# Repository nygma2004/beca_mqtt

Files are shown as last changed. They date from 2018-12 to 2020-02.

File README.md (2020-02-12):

# Beca thermostat Modbus to MQTT Gateway
This sketch is designed to provide an MQTT gateway to Beca Modbus thermostats. It uses a ESP8266 (in my case Wemos D1 mini) and an RS485 to TTL converter to read the Holding Registers of the thermostat and publish those values to MQTT. Also subscirbes to MQTT and relevant updates are written into the Modbus device (like power status, fan speed, mode, target temperature and screen lock).

Project explained in detail in this video: https://youtu.be/d8nhMimx9-0

## Libraries used
- Modbus Master library: https://github.com/4-20ma/ModbusMaster/blob/master/examples/RS485_HalfDuplex/RS485_HalfDuplex.ino
- ESP Software Serial: https://github.com/plerup/espsoftwareserial
- PubSubClient: handle MQTT communication. Install it from the Arduino Library Manager
- Time by Michael Margolis: also install this from the Arduino Library Manager
- SunMoon: sunrise and sunset calculation: https://github.com/sfrwmaker/sunMoon

## Wiring
```
Wemod D1 mini (or other ESP)            TTL to RS485
D1                                      DE
D2                                      RE
D5                                      RO
D6                                      DI
5V                                      VCC
G(GND)                                  GND
```
Red Modbus wire goes to the RS486 "A" screw terminals and black to "B".

## MQTT topic
Root topic is defined in the beginning of the sketch and the full topic gets appended to this. I specified "/beca/" as my root, so my topic are e.g. "/beca/read/power". Values read from the device have "read" in the topic, and values sent to the thermostat have "write". Sending messages to the "read" topics get ignored. There is no error handling on the payload of the "write" messages, data received gets sent to the device.
### Read topics (Published topics)
- root + "read/power": device status, Off (0) or On (1)
- root + "read/fan": fan speed, Auto (0), High (1), Medium (2), Low (3)
- root + "read/mode": mode, Cooling (0), Heating (1), Ventillation (2)
- root + "read/time": hour and time on the device in HH:MM format
- root + "read/weekday": weekday on the device: Monday (1), ... Sunday (7)
- root + "read/valve": valve state, Closed (0), Open (1)
- root + "read/lock" : screen lock, Unlocked (0), Locked (1)
- root + "read/ambient": ambient temperature in degrees centigrade, e.g. 24.5
- root + "read/target": target temperature in degrees centigrade, e.g. 20.5
- root + "rssi": wifi signal strength (RSSI)
- root + "uptime": uptime in minutes
### Write topics (Subscribed topics)
- root + "write/power": set device status (same values as above)
- root + "write/fan": set fan speed (same values as above)
- root + "write/mode": set mode (same values as above)
- root + "write/lock" : set screen lock  (same values as above)
- root + "write/target": set target temperature in degrees centigrade, e.g. 20.5
### Error topic (published)
- root + "error": Modbus error message in text (e.g. "Response timed out")

## Test board shown in the video
This is the general layout of the board showing how the Wemos D1 mini and the RS485 board is oriented:
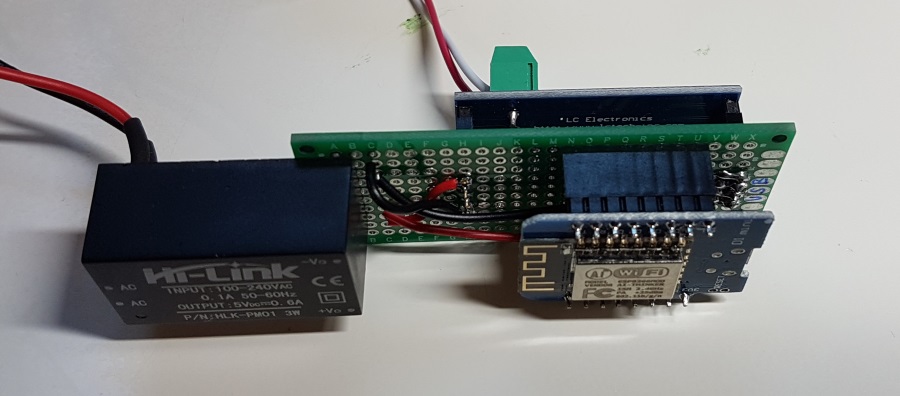
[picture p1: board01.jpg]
General board layout


This is the side where the Wemos plugs in. You see the red +5V wires connected to the 5V pin of the Wemos and Vcc of the RS486 board. Black goes to GND on both:
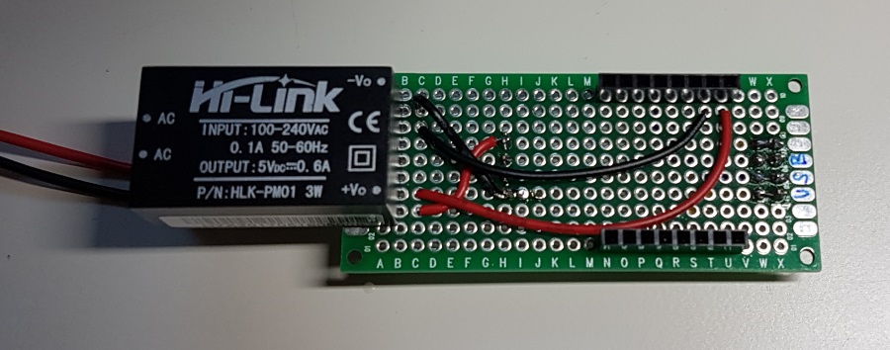
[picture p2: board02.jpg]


And the other side of the board where the RS485 plugs. Yellow wires are the data wires, blue are the enable wires:
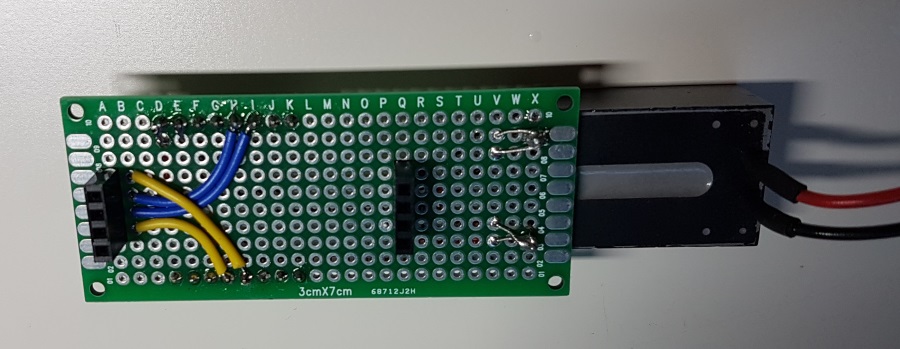
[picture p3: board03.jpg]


## Node-Red
There is an example Node-Red flow (also shown in the video), which shows how to communicate with the device from Node-Red. The flow is in Gitbuh, and also here: https://flows.nodered.org/flow/286a8cea2fbb2a60544f0dd2faefda2a

## PCB
I have also designed a PCB for this board. You can see my PCB project at PCBWay where you can order the PCB but you can also download the gerber files if you want to manufacture elsewhere: https://www.pcbway.com/project/shareproject/ESP8266_Modbus_board.html
You can find the BOM on the PCBWay project page. I purchased most of the components on eBay, but some of the links do not work any more. But only the RS486 to TTL converter is "special" everything else can be found in many different places, like Aliexpress.

## Custom Case
I have design a 3D printable case for the board, you find all the information in the case folder.

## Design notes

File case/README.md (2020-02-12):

This is a 3D printable case for this modbus board. I am not saying this is the most sofisticated case ever. I am fairly new to Fusion 360 as well, so feel free to edit my design and change stuff around. The basic design is parametric, so you can increase the wall thickness or general size, but the mounting points and the wholes are measured from the side, so those need to be re-aligned.
In the files, you find the Fusion 360 model, STL files and gcode as well. Slicing was done for a 3D printer with 0.2 mm layer height, 0.4 mm nozzle, 20% infill with brim.

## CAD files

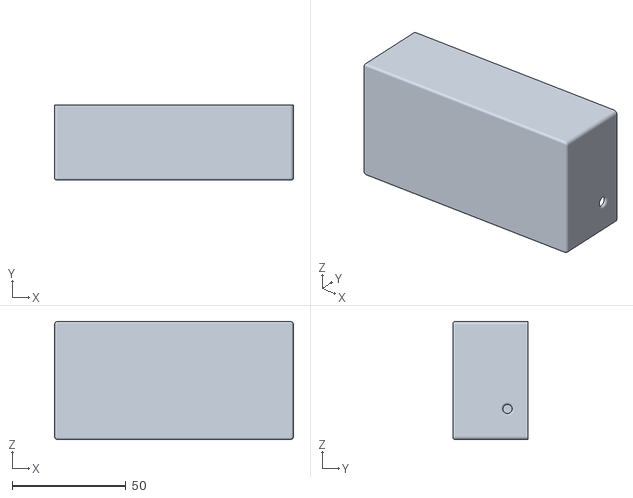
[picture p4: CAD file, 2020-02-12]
case/modbus_case_body.stl
105.0 x 33.0 x 52.0

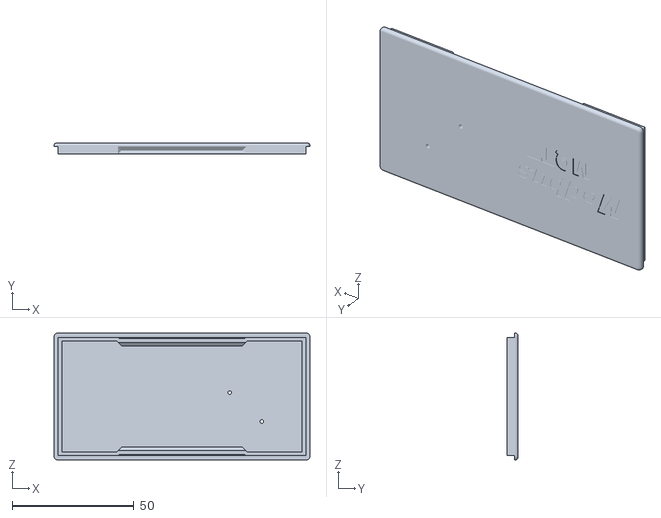
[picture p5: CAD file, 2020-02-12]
case/modbus_case_top.stl
105.0 x 4.50 x 52.0

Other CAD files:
case/Modbus case.f3d

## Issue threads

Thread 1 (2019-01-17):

Issue on NodeMCU

jongerenchaos, 2019-01-17:
I upload the code to my node MCU ESP12E (with arduino version 1.8.5 with esp8266 boardversion 2.4.2). Compiling is OK en uploading is no problem.

But when i run the software i get a error. Can you help me to resolve this issue?

`Beca Modbus to MQTT Gateway
Connecting to Wifi........
Connected to wifi network
IP address: 192.168.1.137
Signal [RSSI]: -38
Modbus connection is set up
MDNS responder started
HTTP server started
Starting UDP
Local port: 2390
Requesting NTP update from 212.92.16.193
Sending NTP packet...
Attempting MQTT connection...connected
NTP Update (epoch): 1547765862
NTP Update (time): 17-01-2019 22:57:42
Modbus minute update failed: Response timed out
Error: Response timed out

Exception (9):
epc1=0x40104b14 epc2=0x00000000 epc3=0x00000000 excvaddr=0x00000003 depc=0x00000000

ctx: sys
sp: 3fffec00 end: 3fffffb0 offset: 01a0

>>>stack>>>
3fffeda0:  0024dce3 00000494 3fff1984 40205409
3fffedb0:  3fffee50 7fffffff 0000025c 00000021
3fffedc0:  3ffef674 0000001f 00000002 40209364
3fffedd0:  0000001f 000012b8 00000257 00000005
3fffede0:  3fffc278 40101fe8 3ffef674 3fff1cd4
3fffedf0:  00000000 00000012 3ffef674 402095b8
3fffee00:  40104d40 0026cec4 3fff0318 00000000
3fffee10:  3ffeef30 3fff0318 3fff0420 3fff0400
3fffee20:  00000000 0026c8aa 40201504 00000005
3fffee30:  3fff0318 000000e2 3fff0400 40209f50
3fffee40:  3fff08b4 3ffe8bb8 000000e2 40202c65
3fffee50:  6365622f 72652f61 00726f72 3fff1494
3fffee60:  00000000 3fff1c5c 3fff1cc8 40218c08
3fffee70:  00000000 4bc6a7f0 f1a9fbe7 00000000
3fffee80:  00001810 00000000 4bc6a7f0 00000000
3fffee90:  40229fb5 00186a00 401067a8 40209cdf
3fffeea0:  3fff1cd4 0000001f 00000012 4020b290
3fffeeb0:  000000e2 3ffef508 3fff0420 40202f8a
3fffeec0:  3fff03fc 0000000a 401067a8 00001808
3fffeed0:  00000000 3ffe98fc 3fff0a6c 40212ec8
3fffeee0:  001bc98c 3ffe9a84 00000041 3fff0570
3fffeef0:  40213004 3fff0574 3ffe98fc 60000600
3fffef00:  005ddcb9 3fff0574 3ffeef08 40213095
3fffef10:  40104b6e 3fff016c 0017fde0 00000000
3fffef20:  40231878 3fff016c 3ffeef30 60000600
3fffef30:  005ddcb9 3ffeef30 3fff016c 40231885
3fffef40:  402318ca 3fffdab0 00000000 3fffdcb0
3fffef50:  3ffeef50 3fffdab0 00000000 4020ab0b
3fffef60:  40000f49 40000f49 3fffdab0 40000f49
3fffef70:  40000e19 40001878 00000002 0000000d
3fffef80:  3fffff10 aa55aa55 000000b4 40104424
3fffef90:  4010442a 00000002 0000000d 0c634b24
3fffefa0:  4010000d 3415490f 4de23e89 7f0d72e0
3fffefb0:  40100774 3fffef4c 40100721 3ffffee8
3fffefc0:  3fffffd0 00000000 00000000 feefeffe
3fffefd0:  feefeffe feefeffe feefeffe feefeffe
3fffefe0:  feefeffe feefeffe feefeffe feefeffe
3fffeff0:  feefeffe feefeffe feefeffe feefeffe
3ffff000:  feefeffe feefeffe feefeffe feefeffe
3ffff010:  feefeffe feefeffe feefeffe feefeffe
3ffff020:  feefeffe feefeffe feefeffe feefeffe
3ffff030:  feefeffe feefeffe feefeffe feefeffe
3ffff040:  feefeffe feefeffe feefeffe feefeffe
3ffff050:  feefeffe feefeffe feefeffe feefeffe
3ffff060:  feefeffe feefeffe feefeffe feefeffe
3ffff070:  feefeffe feefeffe feefeffe feefeffe
3ffff080:  feefeffe feefeffe feefeffe feefeffe
3ffff090:  feefeffe feefeffe feefeffe feefeffe
3ffff0a0:  feefeffe feefeffe feefeffe feefeffe
3ffff0b0:  feefeffe feefeffe feefeffe feefeffe
3ffff0c0:  feefeffe feefeffe feefeffe feefeffe
3ffff0d0:  feefeffe feefeffe feefeffe feefeffe
3ffff0e0:  feefeffe feefeffe feefeffe feefeffe
3ffff0f0:  feefeffe feefeffe feefeffe feefeffe
3ffff100:  feefeffe feefeffe feefeffe feefeffe
3ffff110:  feefeffe feefeffe feefeffe feefeffe
3ffff120:  feefeffe feefeffe feefeffe feefeffe
3ffff130:  feefeffe feefeffe feefeffe feefeffe
3ffff140:  feefeffe feefeffe feefeffe feefeffe
3ffff150:  feefeffe feefeffe feefeffe feefeffe
3ffff160:  feefeffe feefeffe feefeffe feefeffe
3ffff170:  feefeffe feefeffe feefeffe feefeffe
3ffff180:  feefeffe feefeffe feefeffe feefeffe
3ffff190:  feefeffe feefeffe feefeffe feefeffe
3ffff1a0:  feefeffe feefeffe feefeffe feefeffe
3ffff1b0:  feefeffe feefeffe feefeffe feefeffe
3ffff1c0:  feefeffe feefeffe feefeffe feefeffe
3ffff1d0:  feefeffe feefeffe feefeffe feefeffe
3ffff1e0:  feefeffe feefeffe feefeffe feefeffe
3ffff1f0:  feefeffe feefeffe feefeffe feefeffe
3ffff200:  feefeffe feefeffe feefeffe feefeffe
3ffff210:  feefeffe feefeffe feefeffe feefeffe
3ffff220:  feefeffe feefeffe feefeffe feefeffe
3ffff230:  feefeffe feefeffe feefeffe feefeffe
3ffff240:  feefeffe feefeffe feefeffe feefeffe
3ffff250:  feefeffe feefeffe feefeffe feefeffe
3ffff260:  feefeffe feefeffe feefeffe feefeffe
3ffff270:  feefeffe feefeffe feefeffe feefeffe
3ffff280:  feefeffe feefeffe feefeffe feefeffe
3ffff290:  feefeffe feefeffe feefeffe feefeffe
3ffff2a0:  feefeffe feefeffe feefeffe feefeffe
3ffff2b0:  feefeffe feefeffe feefeffe feefeffe
3ffff2c0:  feefeffe feefeffe feefeffe feefeffe
3ffff2d0:  feefeffe feefeffe feefeffe feefeffe
3ffff2e0:  feefeffe feefeffe feefeffe feefeffe
3ffff2f0:  feefeffe feefeffe feefeffe feefeffe
3ffff300:  feefeffe feefeffe feefeffe feefeffe
3ffff310:  feefeffe feefeffe feefeffe feefeffe
3ffff320:  feefeffe feefeffe feefeffe feefeffe
3ffff330:  feefeffe feefeffe feefeffe feefeffe
3ffff340:  feefeffe feefeffe feefeffe feefeffe
3ffff350:  feefeffe feefeffe feefeffe feefeffe
3ffff360:  feefeffe feefeffe feefeffe feefeffe
3ffff370:  feefeffe feefeffe feefeffe feefeffe
3ffff380:  feefeffe feefeffe feefeffe feefeffe
3ffff390:  feefeffe feefeffe feefeffe feefeffe
3ffff3a0:  feefeffe feefeffe feefeffe feefeffe
3ffff3b0:  feefeffe feefeffe feefeffe feefeffe
3ffff3c0:  feefeffe feefeffe feefeffe feefeffe
3ffff3d0:  feefeffe feefeffe feefeffe feefeffe
3ffff3e0:  feefeffe feefeffe feefeffe feefeffe
3ffff3f0:  feefeffe feefeffe feefeffe feefeffe
3ffff400:  feefeffe feefeffe feefeffe feefeffe
3ffff410:  feefeffe feefeffe feefeffe feefeffe
3ffff420:  feefeffe feefeffe feefeffe feefeffe
3ffff430:  feefeffe feefeffe feefeffe feefeffe
3ffff440:  feefeffe feefeffe feefeffe feefeffe
3ffff450:  feefeffe feefeffe feefeffe feefeffe
3ffff460:  feefeffe feefeffe feefeffe feefeffe
3ffff470:  feefeffe feefeffe feefeffe feefeffe
3ffff480:  feefeffe feefeffe feefeffe feefeffe
3ffff490:  feefeffe feefeffe feefeffe feefeffe
3ffff4a0:  feefeffe feefeffe feefeffe feefeffe
3ffff4b0:  feefeffe feefeffe feefeffe feefeffe
3ffff4c0:  feefeffe feefeffe feefeffe feefeffe
3ffff4d0:  feefeffe feefeffe feefeffe feefeffe
3ffff4e0:  feefeffe feefeffe feefeffe feefeffe
3ffff4f0:  feefeffe feefeffe feefeffe feefeffe
3ffff500:  feefeffe feefeffe feefeffe feefeffe
3ffff510:  feefeffe feefeffe feefeffe feefeffe
3ffff520:  feefeffe feefeffe feefeffe feefeffe
3ffff530:  feefeffe feefeffe feefeffe feefeffe
3ffff540:  feefeffe feefeffe feefeffe feefeffe
3ffff550:  feefeffe feefeffe feefeffe feefeffe
3ffff560:  feefeffe feefeffe feefeffe feefeffe
3ffff570:  feefeffe feefeffe feefeffe feefeffe
3ffff580:  feefeffe feefeffe feefeffe feefeffe
3ffff590:  feefeffe feefeffe feefeffe feefeffe
3ffff5a0:  feefeffe feefeffe feefeffe feefeffe
3ffff5b0:  feefeffe feefeffe feefeffe feefeffe
3ffff5c0:  feefeffe feefeffe feefeffe feefeffe
3ffff5d0:  feefeffe feefeffe feefeffe feefeffe
3ffff5e0:  feefeffe feefeffe feefeffe feefeffe
3ffff5f0:  feefeffe feefeffe feefeffe feefeffe
3ffff600:  feefeffe feefeffe feefeffe feefeffe
3ffff610:  feefeffe feefeffe feefeffe feefeffe
3ffff620:  feefeffe feefeffe feefeffe feefeffe
3ffff630:  feefeffe feefeffe feefeffe feefeffe
3ffff640:  feefeffe feefeffe feefeffe feefeffe
3ffff650:  feefeffe feefeffe feefeffe feefeffe
3ffff660:  feefeffe feefeffe feefeffe feefeffe
3ffff670:  feefeffe feefeffe feefeffe feefeffe
3ffff680:  feefeffe feefeffe feefeffe feefeffe
3ffff690:  feefeffe feefeffe feefeffe feefeffe
3ffff6a0:  feefeffe feefeffe feefeffe feefeffe
3ffff6b0:  feefeffe feefeffe feefeffe feefeffe
3ffff6c0:  feefeffe feefeffe feefeffe feefeffe
3ffff6d0:  feefeffe feefeffe feefeffe feefeffe
3ffff6e0:  feefeffe feefeffe feefeffe feefeffe
3ffff6f0:  feefeffe feefeffe feefeffe feefeffe
3ffff700:  feefeffe feefeffe feefeffe feefeffe
3ffff710:  feefeffe feefeffe feefeffe feefeffe
3ffff720:  feefeffe feefeffe feefeffe feefeffe
3ffff730:  feefeffe feefeffe feefeffe feefeffe
3ffff740:  feefeffe feefeffe feefeffe feefeffe
3ffff750:  feefeffe feefeffe feefeffe feefeffe
3ffff760:  feefeffe feefeffe feefeffe feefeffe
3ffff770:  feefeffe feefeffe feefeffe feefeffe
3ffff780:  feefeffe feefeffe feefeffe feefeffe
3ffff790:  feefeffe feefeffe feefeffe feefeffe
3ffff7a0:  feefeffe feefeffe feefeffe feefeffe
3ffff7b0:  feefeffe feefeffe feefeffe feefeffe
3ffff7c0:  feefeffe feefeffe feefeffe feefeffe
3ffff7d0:  feefeffe feefeffe feefeffe feefeffe
3ffff7e0:  feefeffe feefeffe feefeffe feefeffe
3ffff7f0:  feefeffe feefeffe feefeffe feefeffe
3ffff800:  feefeffe feefeffe feefeffe feefeffe
3ffff810:  feefeffe feefeffe feefeffe feefeffe
3ffff820:  feefeffe feefeffe feefeffe feefeffe
3ffff830:  feefeffe feefeffe feefeffe feefeffe
3ffff840:  feefeffe feefeffe feefeffe feefeffe
3ffff850:  feefeffe feefeffe feefeffe feefeffe
3ffff860:  feefeffe feefeffe feefeffe feefeffe
3ffff870:  feefeffe feefeffe feefeffe feefeffe
3ffff880:  feefeffe feefeffe feefeffe feefeffe
3ffff890:  feefeffe feefeffe feefeffe feefeffe
3ffff8a0:  feefeffe feefeffe feefeffe feefeffe
3ffff8b0:  feefeffe feefeffe feefeffe feefeffe
3ffff8c0:  feefeffe feefeffe feefeffe feefeffe
3ffff8d0:  feefeffe feefeffe feefeffe feefeffe
3ffff8e0:  feefeffe feefeffe feefeffe feefeffe
3ffff8f0:  feefeffe feefeffe feefeffe feefeffe
3ffff900:  feefeffe feefeffe feefeffe feefeffe
3ffff910:  feefeffe feefeffe feefeffe feefeffe
3ffff920:  feefeffe feefeffe feefeffe feefeffe
3ffff930:  feefeffe feefeffe feefeffe feefeffe
3ffff940:  feefeffe feefeffe feefeffe feefeffe
3ffff950:  feefeffe feefeffe feefeffe feefeffe
3ffff960:  feefeffe feefeffe feefeffe feefeffe
3ffff970:  feefeffe feefeffe feefeffe feefeffe
3ffff980:  feefeffe feefeffe feefeffe feefeffe
3ffff990:  feefeffe feefeffe feefeffe feefeffe
3ffff9a0:  feefeffe feefeffe feefeffe feefeffe
3ffff9b0:  feefeffe feefeffe feefeffe feefeffe
3ffff9c0:  feefeffe feefeffe feefeffe feefeffe
3ffff9d0:  feefeffe feefeffe feefeffe feefeffe
3ffff9e0:  feefeffe feefeffe feefeffe feefeffe
3ffff9f0:  feefeffe feefeffe feefeffe feefeffe
3ffffa00:  feefeffe feefeffe feefeffe feefeffe
3ffffa10:  feefeffe feefeffe feefeffe feefeffe
3ffffa20:  feefeffe feefeffe feefeffe feefeffe
3ffffa30:  feefeffe feefeffe feefeffe feefeffe
3ffffa40:  feefeffe feefeffe feefeffe feefeffe
3ffffa50:  feefeffe feefeffe feefeffe feefeffe
3ffffa60:  feefeffe feefeffe feefeffe feefeffe
3ffffa70:  feefeffe feefeffe feefeffe feefeffe
3ffffa80:  feefeffe feefeffe feefeffe feefeffe
3ffffa90:  feefeffe feefeffe feefeffe feefeffe
3ffffaa0:  feefeffe feefeffe feefeffe feefeffe
3ffffab0:  feefeffe feefeffe feefeffe feefeffe
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
jongerenchaos, 2019-01-18:
Update: I get the same results with a ESP01 or another ESP device, also with another ESP boardversion or Arduino version

nygma2004, 2019-01-18:
Sorry, I am on a business trip, I could not respond to your query in time. The only time I got a short dump when was before I disabled the watchdog timer. But that is done in code so it should not impact you.

I can see that the rst cause:2 which is the reset pin. Are you using the reset pin for something? It looks like something is pulling the reset pin. Did you wire your module same as mine?

jongerenchaos, 2019-01-18:
Thanks for your fast reply!

Yep the wires are exactly the same as yours. Maybe that i have a thermostat which not support modbus or something (or missing the modbus components)? Can you send some images from the PCB from your thermostat, so that i can add some missing components or something....?

Here are some images from the thermostat who i used:
https://pilo.ovh/image/SpNQg
https://pilo.ovh/image/SpJEx

nygma2004, 2019-01-19:
Oh, so this looks same but not exactly Beca. So mine actually had a red and white wire coming out at the back which was marked modbus. I have never opened the case.

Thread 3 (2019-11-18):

State all the libraries

ngalfas, 2019-11-18:
Hi, just trying your code.  I saw the README stating 2 libraries.
ModbusMaster  which needs to be added to the Arduino IDE and EspSoftware Special which is already  available when ESP8266 installs its board package.

Also there are some more libraries need to be installed.
PubSubClient, Time and sunMoon.

The first two i found on the Libraries Manager.
I can't find the sunMoon Library. There is no such library on the Manager.
Even searched for it but still not sure.
Maybe you can clarify this and add these to the README?

ngalfas, 2019-11-19:
when i had a better look on the code, i saw you commented all the daylight calculations.
so i just removed all of the sunMoon references from the code.

nygma2004, 2019-11-19:
Sorry for the slow response. I have updated the readme.

Closed 2019-11-19.

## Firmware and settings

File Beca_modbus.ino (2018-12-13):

)#include <SoftwareSerial.h>       // Leave the main serial line (USB) for debugging and flashing
#include <ModbusMaster.h>         // Modbus master library for ESP8266
#include <ESP8266WiFi.h>          // Wifi connection
#include <ESP8266WebServer.h>     // Web server for general HTTP response
#include <ESP8266mDNS.h>          // mDNS
#include <PubSubClient.h>         // MQTT support
#include <WiFiUdp.h>                // Added for NTP functionality
#include <Time.h>
#include <TimeLib.h>
#include <sunMoon.h>                // Sunrise, sunset calculation
#include "NTP.h"

#define MODBUS_RATE     9600      // Modbus speed of Beca, do not change
#define SERIAL_RATE     115200    // Serial speed for status info
#define MAX485_DE       5         // D1, DE pin on the TTL to RS485 converter
#define MAX485_RE_NEG   4         // D2, RE pin on the TTL to RS485 converter
#define MAX485_RX       14        // D5, RO pin on the TTL to RS485 converter
#define MAX485_TX       12        // D6, DI pin on the TTL to RS485 converter
#define SLAVE_ID        1         // Default slave ID of Beca
#define STATUS_LED      2         // Status LED on the Wemos D1 mini (D4)
#define UPDATE_MODBUS   1         // 1: modbus device is read every second
#define UPDATE_STATUS   10        // 10: status mqtt message is sent every 10 seconds

// Update the below parameters for your project
// Also check NTP.h for some parameters as well
const char* ssid = "xxxxxxxxxxxxx";           // Wifi SSID
const char* password = "xxxxxxxxxxxxxxxx";    // Wifi password
const char* mqtt_server = "192.168.x.xx";     // MQTT server
const char* mqtt_user = "xxxxxx";             // MQTT userid
const char* mqtt_password = "xxxxxx";         // MQTT password
const char* clientID = "Beca";                // MQTT client ID
const char* topicRoot = "/beca/";             // MQTT root topic for the device, keep / at the end

String NTPtime = "--:--";
char msg[50];
String mqttStat = "";
String message = "";
unsigned long lastTick, uptime, lastNTP, seconds;

os_timer_t myTimer;
MDNSResponder mdns;
ESP8266WebServer server(80);
WiFiClient espClient;
PubSubClient mqtt(mqtt_server, 1883, 0, espClient);
SoftwareSerial modbus(MAX485_RX, MAX485_TX, false, 256); //RX, TX
ModbusMaster beca;

void preTransmission() {
  digitalWrite(MAX485_RE_NEG, 1);
  digitalWrite(MAX485_DE, 1);
}

void postTransmission() {
  digitalWrite(MAX485_RE_NEG, 0);
  digitalWrite(MAX485_DE, 0);
}

void sendModbusError(uint8_t result) {
  String message = "";
  if (result==beca.ku8MBIllegalFunction) {
    message = "Illegal function";
  }
  if (result==beca.ku8MBIllegalDataAddress) {
    message = "Illegal data address";
  }
  if (result==beca.ku8MBIllegalDataValue) {
    message = "Illegal data value";
  }
  if (result==beca.ku8MBSlaveDeviceFailure) {
    message = "Slave device failure";
  }
  if (result==beca.ku8MBInvalidSlaveID) {
    message = "Invalid slave ID";
  }
  if (result==beca.ku8MBInvalidFunction) {
    message = "Invalid function";
  }
  if (result==beca.ku8MBResponseTimedOut) {
    message = "Response timed out";
  }
  if (result==beca.ku8MBInvalidCRC) {
    message = "Invalid CRC";
  }
  if (message=="") {
    message = result;
  }
  Serial.println(message);    
  char topic[80];
  char value[30];
  sprintf(topic,"%serror",topicRoot);
  mqtt.publish(topic, message.c_str());
  delay(5);
}

// This is the 1 second timer callback function
void timerCallback(void *pArg) {
  seconds++;
  // Query the modbus device 
  if (seconds % UPDATE_MODBUS==0) {
    uint8_t result;
    //uint16_t data[6];

    digitalWrite(STATUS_LED, 0);
    ESP.wdtDisable();
    result = beca.readHoldingRegisters(0,10);
    ESP.wdtEnable(1);
    if (result == beca.ku8MBSuccess)   {
      char topic[80];
      char value[10];
      // Power
      sprintf(topic,"%sread/power",topicRoot);
      sprintf(value,"%d",beca.getResponseBuffer(0x00));
      //itoa(beca.getResponseBuffer(0x00),value,10);
      mqtt.publish(topic, value);
      Serial.print(F("Power: "));
      Serial.print(value);
      //yield();
      // Fan
      sprintf(topic,"%sread/fan",topicRoot);
      sprintf(value,"%d",beca.getResponseBuffer(0x01));
      //itoa(beca.getResponseBuffer(0x01),value,10);
      mqtt.publish(topic, value);
      Serial.print(F(", Fan: "));
      Serial.print(value);
      //yield();
      // Mode
      sprintf(topic,"%sread/mode",topicRoot);
      //sprintf(value,"%d",beca.getResponseBuffer(0x02));
      itoa(beca.getResponseBuffer(0x02),value,10);
      mqtt.publish(topic, value);
      Serial.print(F(", Mode: "));
      Serial.print(value);
      //yield();
      // Target temperature
      sprintf(topic,"%sread/target",topicRoot);
      sprintf(value,"%.1f",beca.getResponseBuffer(0x03)/10.0f);
      mqtt.publish(topic, value);
      Serial.print(F(", Target: "));
      Serial.print(value);
      //yield();
      // Ambient
      sprintf(topic,"%sread/ambient",topicRoot);
      sprintf(value,"%.1f",beca.getResponseBuffer(0x08)/10.0f);
      mqtt.publish(topic, value);
      Serial.print(F(", Ambient: "));
      Serial.print(value);
      //yield();
      // Lock
      sprintf(topic,"%sread/lock",topicRoot);
      sprintf(value,"%d",beca.getResponseBuffer(0x04));
      mqtt.publish(topic, value);
      Serial.print(F(", Lock: "));
      Serial.print(value);
      //yield();
      // Valve
      sprintf(topic,"%sread/valve",topicRoot);
      sprintf(value,"%d",beca.getResponseBuffer(0x09));
      mqtt.publish(topic, value);
      Serial.print(F(", Valve: "));
      Serial.print(value);
      //yield();
      // Weekday
      sprintf(topic,"%sread/weekday",topicRoot);
      sprintf(value,"%d",beca.getResponseBuffer(0x07));
      mqtt.publish(topic, value);
      Serial.print(F(", Weekday: "));
      Serial.print(value);
      //yield();
      // Time
      sprintf(topic,"%sread/time",topicRoot);
      sprintf(value,"%02d:%02d",beca.getResponseBuffer(0x06),beca.getResponseBuffer(0x05));
      mqtt.publish(topic, value);
      Serial.print(F(", Time: "));
      Serial.println(value);
    } else {
      Serial.print(F("Error: "));
      sendModbusError(result);
    }
    digitalWrite(STATUS_LED, 1);

  }
  // Send RSSI and uptime status
  if (seconds % UPDATE_STATUS==0) {
    // Send MQTT update
    if (mqtt_server!="") {
      char topic[80];
      char value[10];
      sprintf(topic,"%s%s",topicRoot,"rssi");
      itoa(WiFi.RSSI(),value,10);
      mqtt.publish(topic, value);
      sprintf(topic,"%s%s",topicRoot,"uptime");
      itoa(uptime,value,10);
      mqtt.publish(topic, value);
      Serial.println(F("MQTT status sent"));
    }
  }
}

// MQTT reconnect logic
void reconnect() {
  //String mytopic;
  // Loop until we're reconnected
  while (!mqtt.connected()) {
    Serial.print("Attempting MQTT connection...");
    // Attempt to connect
    if (mqtt.connect(clientID, mqtt_user, mqtt_password)) {
      Serial.println(F("connected"));
      // ... and resubscribe
      char topic[80];
      sprintf(topic,"%swrite/#",topicRoot);
      mqtt.subscribe(topic);
    } else {
      Serial.print(F("failed, rc="));
      Serial.print(mqtt.state());
      Serial.println(F(" try again in 5 seconds"));
      // Wait 5 seconds before retrying
      delay(5000);
    }
  }
}



void setup() {

  Serial.begin(SERIAL_RATE);
  modbus.begin(MODBUS_RATE);
  Serial.println(F("\nBeca Modbus to MQTT Gateway"));
  // Init outputs, RS485 in receive mode
  pinMode(MAX485_RE_NEG, OUTPUT);
  pinMode(MAX485_DE, OUTPUT);
  pinMode(STATUS_LED, OUTPUT);
  digitalWrite(MAX485_RE_NEG, 0);
  digitalWrite(MAX485_DE, 0);

  // Initialize some variables
  uptime = 0;
  seconds = 0;

  // Connect to Wifi
  Serial.print(F("Connecting to Wifi"));
  WiFi.mode(WIFI_STA);
  WiFi.begin(ssid, password);
  while (WiFi.status() != WL_CONNECTED) {
    delay(500);
    Serial.print(F("."));
    seconds++;
    if (seconds>180) {
      // reboot the ESP if cannot connect to wifi
      ESP.restart();
    }
  }
  seconds = 0;
  Serial.println("");
  Serial.println(F("Connected to wifi network"));
  Serial.print(F("IP address: "));
  Serial.println(WiFi.localIP());
  Serial.print(F("Signal [RSSI]: "));
  Serial.println(WiFi.RSSI());

  // Set up the Modbus line
  beca.begin(SLAVE_ID , modbus);
  // Callbacks allow us to configure the RS485 transceiver correctly
  beca.preTransmission(preTransmission);
  beca.postTransmission(postTransmission);
  Serial.println("Modbus connection is set up");

  // Create the 1 second timer interrupt
  os_timer_setfn(&myTimer, timerCallback, NULL);
  os_timer_arm(&myTimer, 1000, true);

  // Set up the MDNS and the HTTP server
  if (mdns.begin("Beca", WiFi.localIP())) {
    Serial.println(F("MDNS responder started"));
  }  
  server.on("/", [](){                        // Dummy page
    server.send(200, "text/plain", "Beca Modbus to MQTT Gateway");
  });
  server.begin();
  Serial.println(F("HTTP server started"));

  // Set up the MQTT server connection
  if (mqtt_server!="") {
    mqtt.setServer(mqtt_server, 1883);
    mqtt.setCallback(callback);
  }

  // Start UDP for NTP function
  Serial.println(F("Starting UDP"));
  udp.begin(localPort);
  Serial.print(F("Local port: "));
  Serial.println(udp.localPort());
  requestNTPUpdate();
  // Initialize sunrise and sunset calculator
  sm.init(GMTOffset, sm_latitude, sm_longtitude);  
  
}



void handleNTPResponse() {
  // Check for NTP response
  int cb = udp.parsePacket();
  if (cb!=0) {
    NTPUpdateMillis = millis();
    NTPRequested = false;
    udp.read(packetBuffer, NTP_PACKET_SIZE); // read the packet into the buffer
    unsigned long highWord = word(packetBuffer[40], packetBuffer[41]);
    unsigned long lowWord = word(packetBuffer[42], packetBuffer[43]);
    unsigned long secsSince1900 = highWord << 16 | lowWord;
    const unsigned long seventyYears = 2208988800UL;
    epoch = secsSince1900 - seventyYears;
    if (summerTime(epoch)) {
      epoch += 3600; // add 1 hour DST
    }
    epoch += GMTOffset * 60;
    Serial.print(F("NTP Update (epoch): "));
    Serial.println(epoch);
    Serial.print(F("NTP Update (time): "));
    printDate(epoch);  Serial.println("");

    // Send the updates to the modbus device
    uint8_t result;
    digitalWrite(STATUS_LED, 0);
    ESP.wdtDisable();
    result = beca.writeSingleRegister(5,getMinute(epoch));
    ESP.wdtEnable(1);
    if (result!=beca.ku8MBSuccess) {
      Serial.print(F("Modbus minute update failed: "));
      sendModbusError(result);
    }
    delay(5); // Added this delay as sometimes the not all registers got updated on the device
    ESP.wdtDisable();
    result = beca.writeSingleRegister(6,getHour(epoch));
    ESP.wdtEnable(1);
    if (result!=beca.ku8MBSuccess) {
      Serial.print(F("Modbus hour update failed: "));
      sendModbusError(result);
    }
    delay(5);
    ESP.wdtDisable();
    result = beca.writeSingleRegister(7,calcDayOfWeek(epoch));
    ESP.wdtEnable(1);
    if (result!=beca.ku8MBSuccess) {
      Serial.print(F("Modbus weekday update failed: "));
      sendModbusError(result);
    }
    digitalWrite(STATUS_LED, 1);

/*
    // Sunrise and Sunset calculations
    time_t sRise = sm.sunRise(epoch);
    time_t sSet  = sm.sunSet(epoch);
    if (summerTime(epoch)) {
      sRise += 3600; // add 1 hour DST
      sSet += 3600; // add 1 hour DST
    }
    renderTime();
    Serial.print(F("Today sunrise and sunset: "));
    printDate(sRise); Serial.print(F("; "));
    printDate(sSet);  Serial.println("");
*/
  }  
}

void callback(char* topic, byte* payload, unsigned int length) {
  // Convert the incoming byte array to a string
  String mytopic = (char*)topic;
  payload[length] = '\0'; // Null terminator used to terminate the char array
  String message = (char*)payload;

  Serial.print(F("Message arrived on topic: ["));
  Serial.print(topic);
  Serial.print(F("], "));
  Serial.println(message);


  char checktopic[80];
  uint8_t result;
  // Update the power register
  if (mytopic==(String)topicRoot+"write/power") {
     digitalWrite(STATUS_LED, 0);
     ESP.wdtDisable();
     result = beca.writeSingleRegister(0,atoi((char*)payload));
     ESP.wdtEnable(1);
     if (result == beca.ku8MBSuccess)   {
        Serial.println("Power updated");
     } else {
        Serial.print("Power update failed: ");
        sendModbusError(result);
     }
     digitalWrite(STATUS_LED, 1);
  }

  // Update the fan register
  if (mytopic==(String)topicRoot+"write/fan") {
     digitalWrite(STATUS_LED, 0);
     ESP.wdtDisable();
     result = beca.writeSingleRegister(1,atoi((char*)payload));
     ESP.wdtEnable(1);
     if (result == beca.ku8MBSuccess)   {
        Serial.println("Fan updated");
     } else {
        Serial.print("Fan update failed: ");
        sendModbusError(result);
     }
     digitalWrite(STATUS_LED, 1);
  }

  // Update the mode register
  if (mytopic==(String)topicRoot+"write/mode") {
     digitalWrite(STATUS_LED, 0);
     ESP.wdtDisable();
     result = beca.writeSingleRegister(2,atoi((char*)payload));
     ESP.wdtEnable(1);
     if (result == beca.ku8MBSuccess)   {
        Serial.println("Mode updated");
     } else {
        Serial.print("Mode update failed: ");
        sendModbusError(result);
     }
     digitalWrite(STATUS_LED, 1);
  }

  // Update the lock register
  if (mytopic==(String)topicRoot+"write/lock") {
     digitalWrite(STATUS_LED, 0);
     ESP.wdtDisable();
     result = beca.writeSingleRegister(4,atoi((char*)payload));
     ESP.wdtEnable(1);
     if (result == beca.ku8MBSuccess)   {
        Serial.println("Lock updated");
     } else {
        Serial.print("Lock update failed: ");
        sendModbusError(result);
     }
     digitalWrite(STATUS_LED, 1);
  }

  // Update the target temperature register
  if (mytopic==(String)topicRoot+"write/target") {
     digitalWrite(STATUS_LED, 0);
     ESP.wdtDisable();
     result = beca.writeSingleRegister(3,atof((char*)payload)*10);
     ESP.wdtEnable(1);
     if (result == beca.ku8MBSuccess)   {
        Serial.println("Target temperature updated");
     } else {
        Serial.print("Target temperature update failed: ");
        sendModbusError(result);
     }
     digitalWrite(STATUS_LED, 1);
  }
}

void loop() {
  // Handle HTTP server requests
  server.handleClient();

  // Handle MQTT connection/reconnection
  if (mqtt_server!="") {
    if (!mqtt.connected()) {
      reconnect();
    }
    mqtt.loop();
  }

  // Uptime calculation
  if (millis() - lastTick >= 60000) {            
    lastTick = millis();            
    uptime++;            
  }    


  // Check if NTP update is due
  if ((millis() - NTPUpdateMillis >= 60*60*1000) && (!NTPRequested)) {  
    requestNTPUpdate();
  }    
  // Handle NTP response
  handleNTPResponse();

}

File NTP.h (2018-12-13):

/*
 ************** HEADER DECLARATION *************
#include <WiFiUdp.h>                // Added for NTP functionality
#include <Time.h>
#include <TimeLib.h>
#include <sunMoon.h>                // Sunrise, sunset calculation

 ************** Add to Setup *******************
  // Start UDP for NTP function
  Serial.println("Starting UDP");
  udp.begin(localPort);
  Serial.print("Local port: ");
  Serial.println(udp.localPort());
  requestNTPUpdate();
  // Initialize sunrise and sunset calculator
  sm.init(GMTOffset, sm_latitude, sm_longtitude);

 ************** Add to Loop ********************
  // Check if NTP update is due
  if ((millis() - NTPUpdateMillis >= 60*60*1000) && (!NTPRequested)) {  
    requestNTPUpdate();
  }    

  // Check for NTP response
  int cb = udp.parsePacket();
  if (cb!=0) {
    NTPUpdateMillis = millis();
    NTPRequested = false;
    udp.read(packetBuffer, NTP_PACKET_SIZE); // read the packet into the buffer
    unsigned long highWord = word(packetBuffer[40], packetBuffer[41]);
    unsigned long lowWord = word(packetBuffer[42], packetBuffer[43]);
    unsigned long secsSince1900 = highWord << 16 | lowWord;
    const unsigned long seventyYears = 2208988800UL;
    epoch = secsSince1900 - seventyYears;
    if (summerTime(epoch)) {
      epoch += 3600; // add 1 hour DST
    }
    epoch += GMTOffset * 60;
    Serial.print("NTP Update (epoch): ");
    Serial.println(epoch);
    Serial.print("NTP Update (time): ");
    printDate(epoch);  Serial.println("");

    // Sunrise and Sunset calculations
    time_t sRise = sm.sunRise(epoch);
    time_t sSet  = sm.sunSet(epoch);
    sRise += epoch / 86400L * 86400L;
    sSet += epoch / 86400L * 86400L;
    if (summerTime(epoch)) {
      sRise += 3600; // add 1 hour DST
      sSet += 3600; // add 1 hour DST
    }
    Serial.print("Today sunrise and sunset: ");
    printDate(sRise); Serial.print("; ");
    printDate(sSet);  Serial.println("");
  }  

 */

// Update the below global variables for your project
const char* ntpServerName = "hu.pool.ntp.org";
int GMTOffset = 60;                      // Offset to GMT time in minutes, CET: GMT+1 hour = 60 minutes
long sm_latitude = 47.44;                // Your coordinates, get it from: http://www.mapseasy.com/adress-to-gps-coordinates.php
long sm_longtitude = 19.02;

unsigned long NTPUpdateMillis = 0;       // Last time NTP update was received
bool NTPRequested = false;               // flag that NTP update requested
unsigned long epoch = 0;                 // Unix time received from NTP
unsigned int localPort = 2390;           // local port to listen for UDP packets
const int NTP_PACKET_SIZE = 48;         
byte packetBuffer[ NTP_PACKET_SIZE];

IPAddress timeServerIP;
WiFiUDP udp;
sunMoon  sm;

static const uint8_t monthDays[] = {31, 28, 31, 30, 31, 30, 31, 31, 30, 31, 30, 31};
#define LEAP_YEAR(Y) ( ((1970+Y)>0) && !((1970+Y)%4) && ( ((1970+Y)%100) || !((1970+Y)%400) ) )


struct  strDateTime
{
  byte hour;
  byte minute;
  byte second;
  int year;
  byte month;
  byte day;
  byte wday;
} ;

strDateTime DateTime;                      // Global DateTime structure, will be refreshed every Second

void printDate(time_t date) {
  char buff[20];
  sprintf(buff, "%02d-%02d-%4d %02d:%02d:%02d",
  day(date), month(date), year(date), hour(date), minute(date), second(date));
  Serial.print(buff);
}

void printTime(time_t date) {
  char buff[20];
  sprintf(buff, "%02d:%02d:%02d", hour(date), minute(date), second(date));
  Serial.print(buff);
}

byte getHour(time_t date) {
  return hour(date);
}

byte getMinute(time_t date) {
  return minute(date);
}

byte calcDayOfWeek (time_t date) {
  int y;
  int m;
  int d;
  m = month(date);
  y = year(date)-2000;
  d = day(date);  
  // Old mental arithmetic method for calculating day of week
  // adapted for Arduino, for years 2000~2099
  // returns 1 for Sunday, 2 for Monday, etc., up to 7 for Saturday
  // for "bad" dates (like Feb. 30), it returns 0
  // Note: input year (y) should be a number from 0~99
  if (y > 99) return 0; // we don't accept years after 2099
  // we take care of bad months later
  if (d < 1) return 0; // because there is no day 0
  byte w = 6; // this is a magic number (y2k fix for this method)
  // one ordinary year is 52 weeks + 1 day left over
  // a leap year has one more day than that
  // we add in these "leftover" days
  w += (y + (y >> 2));
  // correction for Jan. and Feb. of leap year
  if (((y & 3) == 0) && (m <= 2)) w--;
  // add in "magic number" for month
  switch (m) {
    case 1:  if (d > 31) return 0; w += 1; break;
    case 2:  if (d > ((y & 3) ? 28 : 29)) return 0; w += 4; break;
    case 3:  if (d > 31) return 0; w += 4; break;
    case 4:  if (d > 30) return 0; break;
    case 5:  if (d > 31) return 0; w += 2; break;
    case 6:  if (d > 30) return 0; w += 5; break;
    case 7:  if (d > 31) return 0; break;
    case 8:  if (d > 31) return 0; w += 3; break;
    case 9:  if (d > 30) return 0; w += 6; break;
    case 10: if (d > 31) return 0; w += 1; break;
    case 11: if (d > 30) return 0; w += 4; break;
    case 12: if (d > 31) return 0; w += 6; break;
    default: return 0;
  }
  // then add day of month
  w += d;
  // there are only 7 days in a week, so we "cast out" sevens
  while (w > 7) w = (w >> 3) + (w & 7);
  w--;
  if (w==0) {
    w = 7; // Beca expects 7 for Sunday
  }
  
  return w;
}

unsigned long getDayOfWeek(time_t date) {
// returns the day of week, 1 Monday, 7 Sunday
/*
  unsigned long dn;
  int y;
  int m;
  int d;
  byte dow;
  m = month(date);
  y = year(date);
  d = day(date);
  m = (m + 9) % 12;
  y -= m / 10;
  dn = 365*y + y/4 - y/100 + y/400 + (m*306 + 5)/10 + (d - 1);

  dow = (dn - 2) % 7;
  if (dow==0) {
    dow = 7; // Beca expects 7 for Sunday
  }
  return dow;
*/

  unsigned long y;
  unsigned long  m;
  unsigned long  d;
  unsigned long f;
  unsigned long g;
  unsigned long n;
  m = month(date);
  y = year(date);
  d = day(date);
  
 if ( m <= 2)
  f = y - 1;
 else
  f = y;
  
 if ( m <= 2)
  g = m +13;
 else
  g = m +1;

   n = 1461 * f / 4 + 153 * g / 5 + d;
    n = n - 621049 % 7;
      if (n==0) {
    n = 7; // Beca expects 7 for Sunday
  }
  return n;
}
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
